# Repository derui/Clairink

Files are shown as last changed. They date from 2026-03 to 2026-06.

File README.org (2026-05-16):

* Clairink
This is a split keyboard having these features:

- ZMK firmware
- 3D printed keyboard case & Rotally encoder nob
  - You can manage behavior with ZMK
- Focus Thocky sound with the Lofree's Phantom switch
- all wireless
- able to use rechageable AAA battery x2
  - I use eneloop for this

* Bill Of Materials

| Name                                   | Qty |
|----------------------------------------+-----|
| SeeedStudio XIAO nRF52480              |   2 |
| AAA battery holder                     |   4 |
| M2 nut                                 |  12 |
| M2 screw                               |  12 |
| AE-XCL102D333CR-G                      |   2 |
| 1N4148W                                |  64 |
| Choc V2 Socket                         |  42 |
| Rotally Encoder (ALPS EC12 compatible) |   2 |
| SS-12D01G3                             |   2 |
| chip condenser (0.1uF)                 |   4 |
| chip register (2.2KΩ)                  |   4 |

* LICENSE
MIT

** LICENSE note
This keyboard uses Seeed Studio's XIAO nRF52480 kicad symbol and footprint. There are licensed under MIT that they written in [[https://wiki.seeedstudio.com/ja/License/][here]].

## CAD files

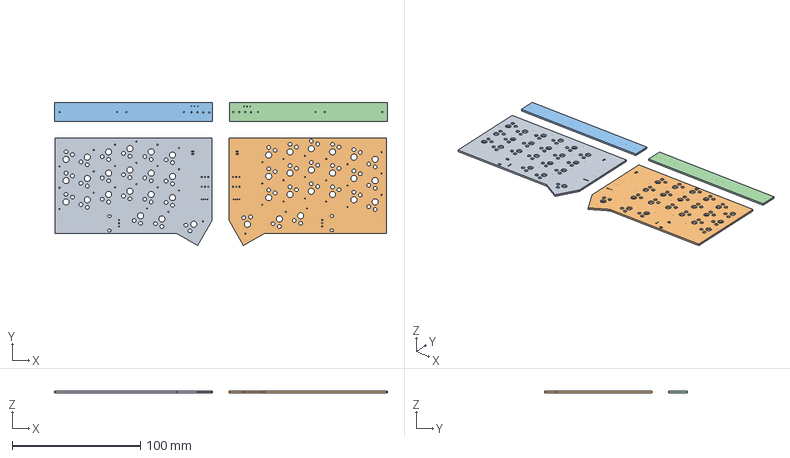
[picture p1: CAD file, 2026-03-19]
assemble.step
259.6 x 111.5 x 1.51 mm
assemble_PCB_1
assemble_PCB_2
assemble_PCB_3
assemble_PCB_4

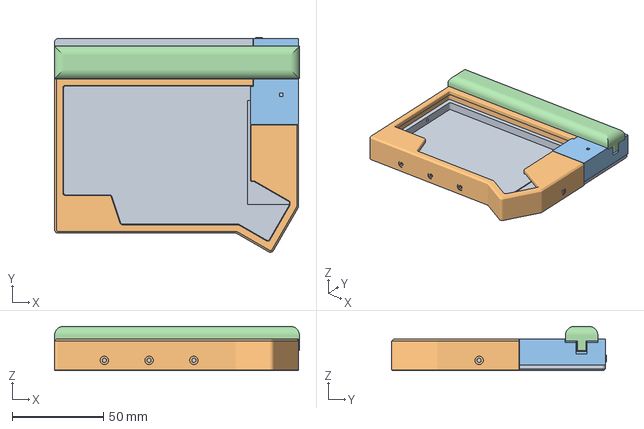
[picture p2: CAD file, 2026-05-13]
case-v1_3-finish.3mf
134.1 x 117.5 x 24.3 mm

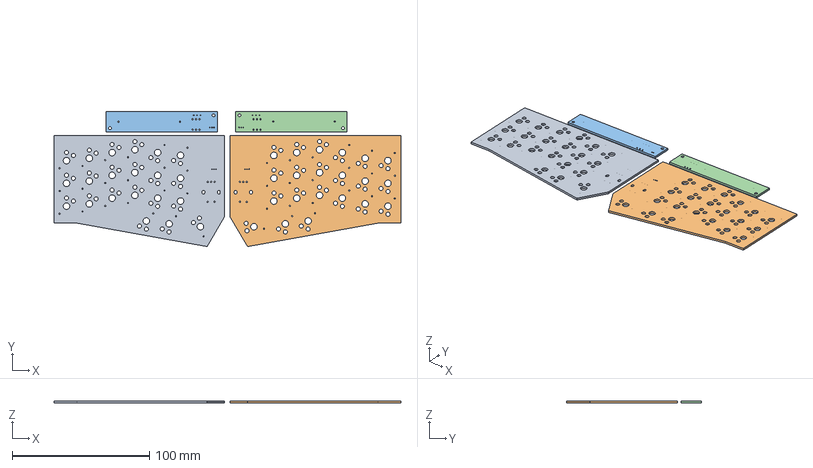
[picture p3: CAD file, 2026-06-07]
v2/assemble-final/base.step
252.6 x 98.4 x 1.51 mm
assemble_PCB_1
assemble_PCB_2
assemble_PCB_3
assemble_PCB_4

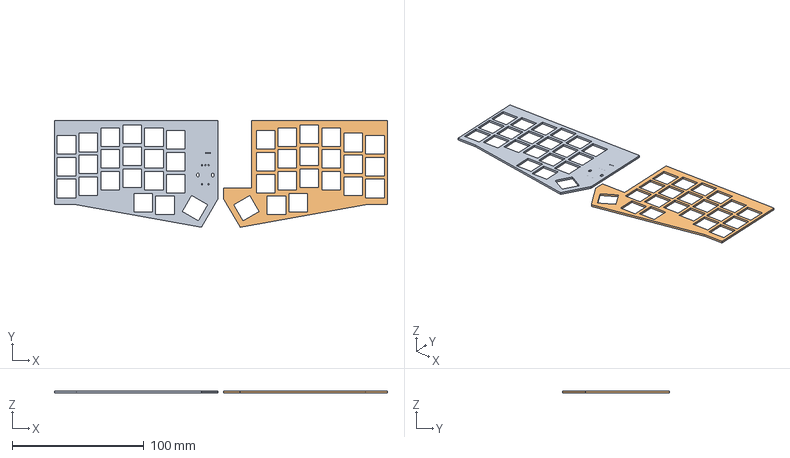
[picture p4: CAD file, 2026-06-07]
v2/switch-plate/base.step
252.6 x 80.8 x 1.51 mm
switch-plate_PCB_1
switch-plate_PCB_2

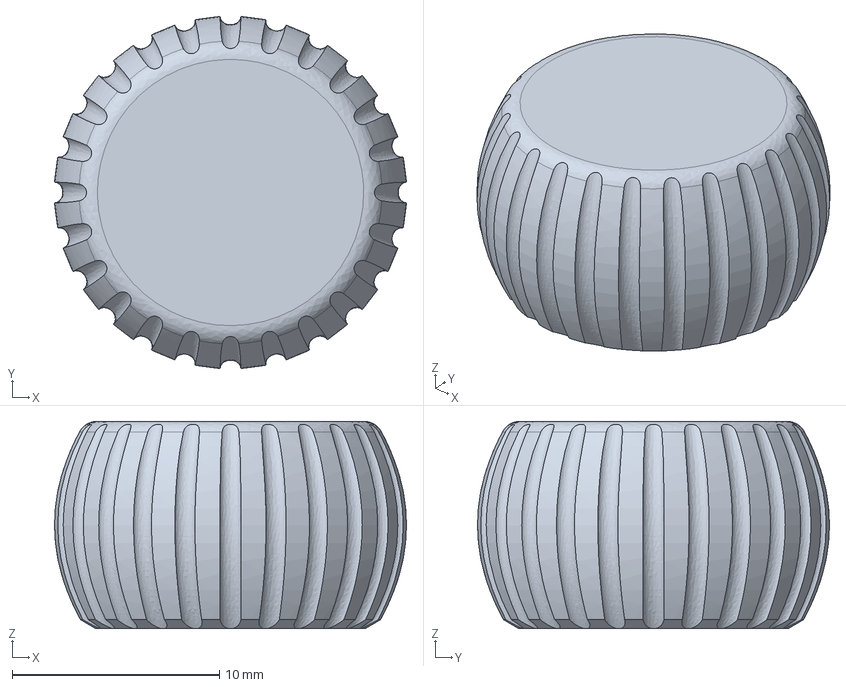
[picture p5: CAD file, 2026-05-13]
encoder-nob.FCStd
17.0 x 17.0 x 10.0 mm

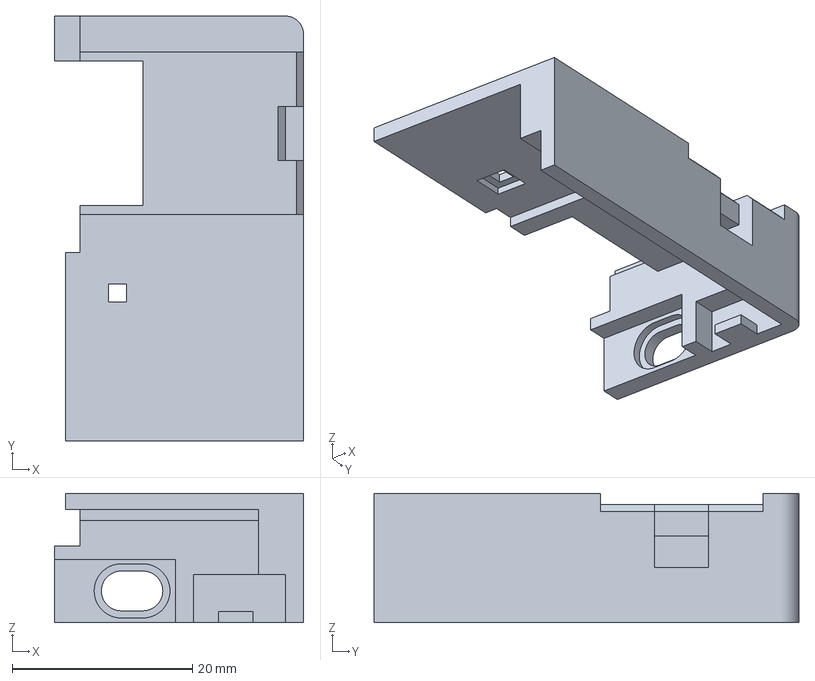
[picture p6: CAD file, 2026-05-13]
case-v1_3-finish_right-micom cover.3mf
27.6 x 47.1 x 14.3 mm

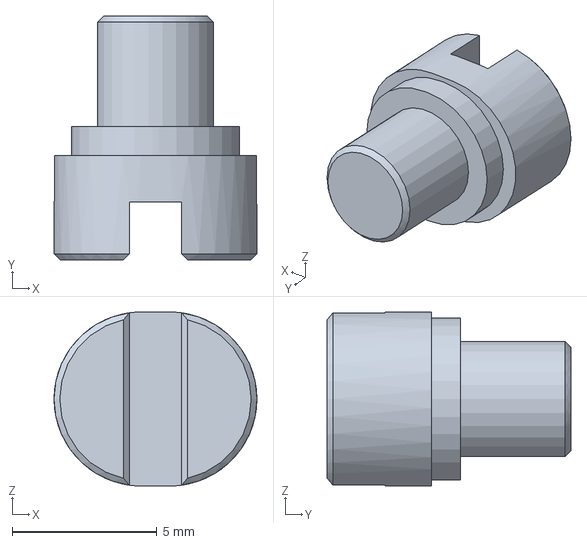
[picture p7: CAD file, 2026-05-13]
case-v1_3-finish-switch.3mf
7.00 x 8.40 x 6.00 mm

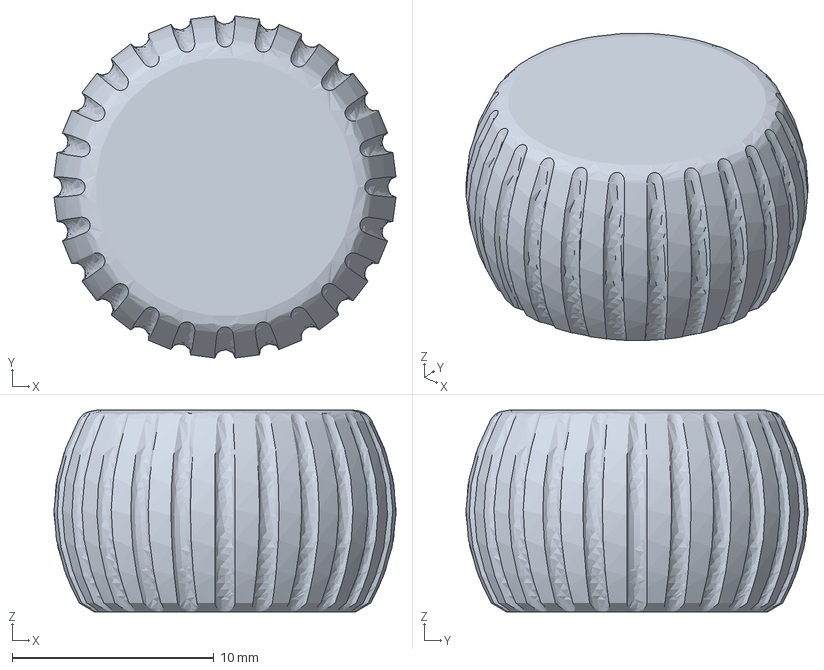
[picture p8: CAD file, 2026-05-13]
encoder-nob-Cut.3mf
17.0 x 17.0 x 10.0 mm

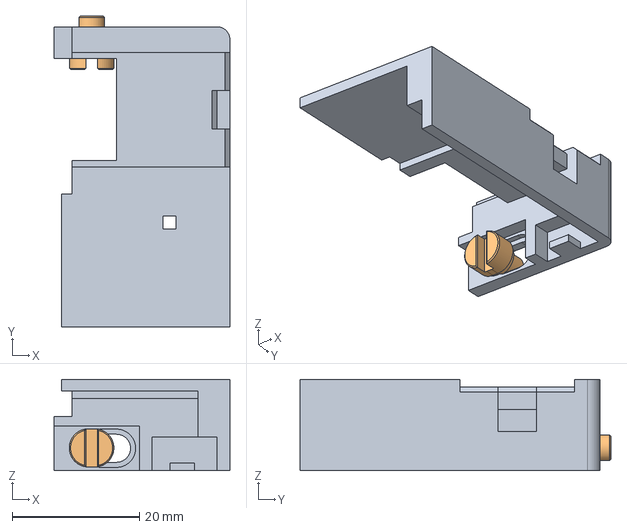
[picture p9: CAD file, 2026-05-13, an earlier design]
v1/case/case-v1_3-finish.FCStd
27.6 x 48.8 x 14.3 mm
micom cover
switch

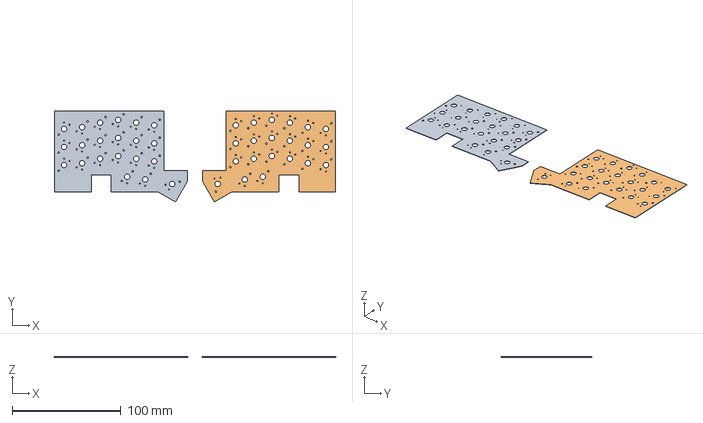
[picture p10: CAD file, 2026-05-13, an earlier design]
v1/switch-foam/switch-foam.step
258.6 x 83.7 x 0.31 mm
switch-foam_PCB_1
switch-foam_PCB_2

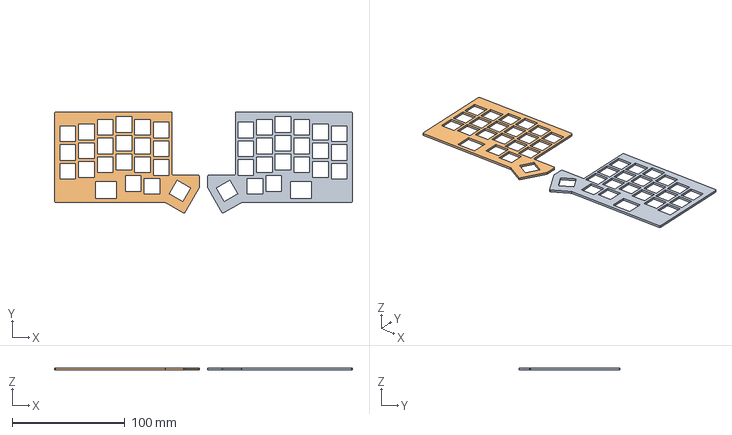
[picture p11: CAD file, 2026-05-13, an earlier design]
v1/switch-plate/switch-plate.step
264.6 x 89.9 x 1.91 mm
switch-plate_PCB_1
switch-plate_PCB_2

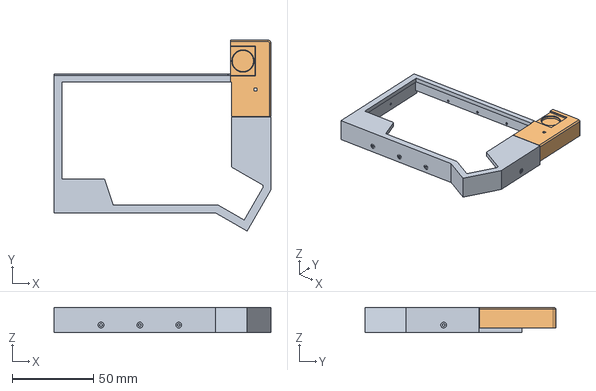
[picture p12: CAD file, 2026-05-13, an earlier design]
v1/case/case-v1-finish.FCStd
133.6 x 117.7 x 15.5 mm
top
micom cover

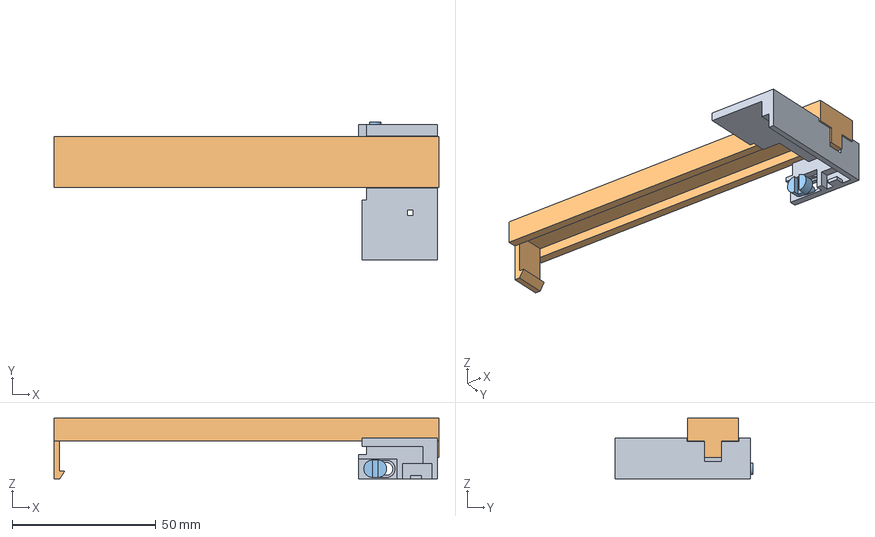
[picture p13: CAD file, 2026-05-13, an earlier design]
v1/case/case-v1_3.FCStd
134.1 x 48.0 x 21.2 mm
micom cover
battery cover
switch

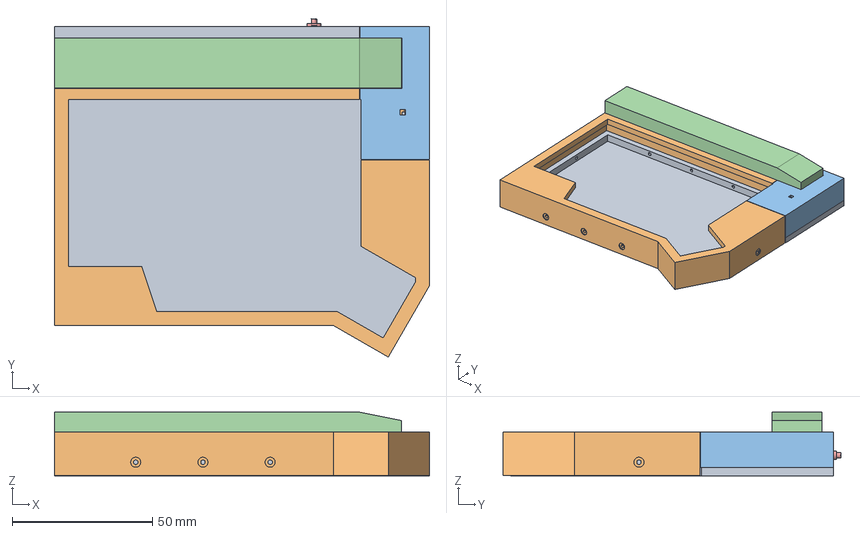
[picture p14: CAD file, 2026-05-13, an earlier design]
v1/case/case-v1.FCStd
133.6 x 120.5 x 22.7 mm
bottom
top
micom cover
battery cover
switch
BOSS-EXTRUDE14_8_
BOSS-EXTRUDE7_4_
BOSS-EXTRUDE7_3_
BOSS-EXTRUDE14_4_
BOSS-EXTRUDE14_2_
BOSS-EXTRUDE14_11_
BOSS-EXTRUDE7_7_
BOSS-EXTRUDE14_9_
BOSS-EXTRUDE14_3_
BOSS-EXTRUDE14_7_
MIRROR2
BOSS-EXTRUDE14_5_
BOSS-EXTRUDE14_12_
BOSS-EXTRUDE7_8_
BOSS-EXTRUDE7_1_
BOSS-EXTRUDE14_10_
BOSS-EXTRUDE7_9_
BOSS-EXTRUDE14_6_
BOSS-EXTRUDE14_1_
BOSS-EXTRUDE7_6_
BOSS-EXTRUDE7_2_
CUT-EXTRUDE5
BOSS-EXTRUDE7_5_
Shield
Pins
Pins001
Pins002
Pins003
CAP
CAP001
CAP002
ANT1
ANT001
ANT002
Silkscreen
Silkscreen001
Silkscreen002
Silkscreen003
Silkscreen004
Silkscreen005
Silkscreen006
Silkscreen007
Silkscreen008
Silkscreen009
Silkscreen010
Silkscreen011
Silkscreen012
CAP004
CAP005
CAP006
CAP 3
CAP 001
CAP 002
LED
LED001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

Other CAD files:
case-v1_3-finish-micom cover.3mf
v1/case/case-v1_2.FCStd
v1/case/case-v1_2-finish.FCStd
v1/case/case-v1_3-finish_right.FCStd
v1/case/case-v1_3-finish.3mf

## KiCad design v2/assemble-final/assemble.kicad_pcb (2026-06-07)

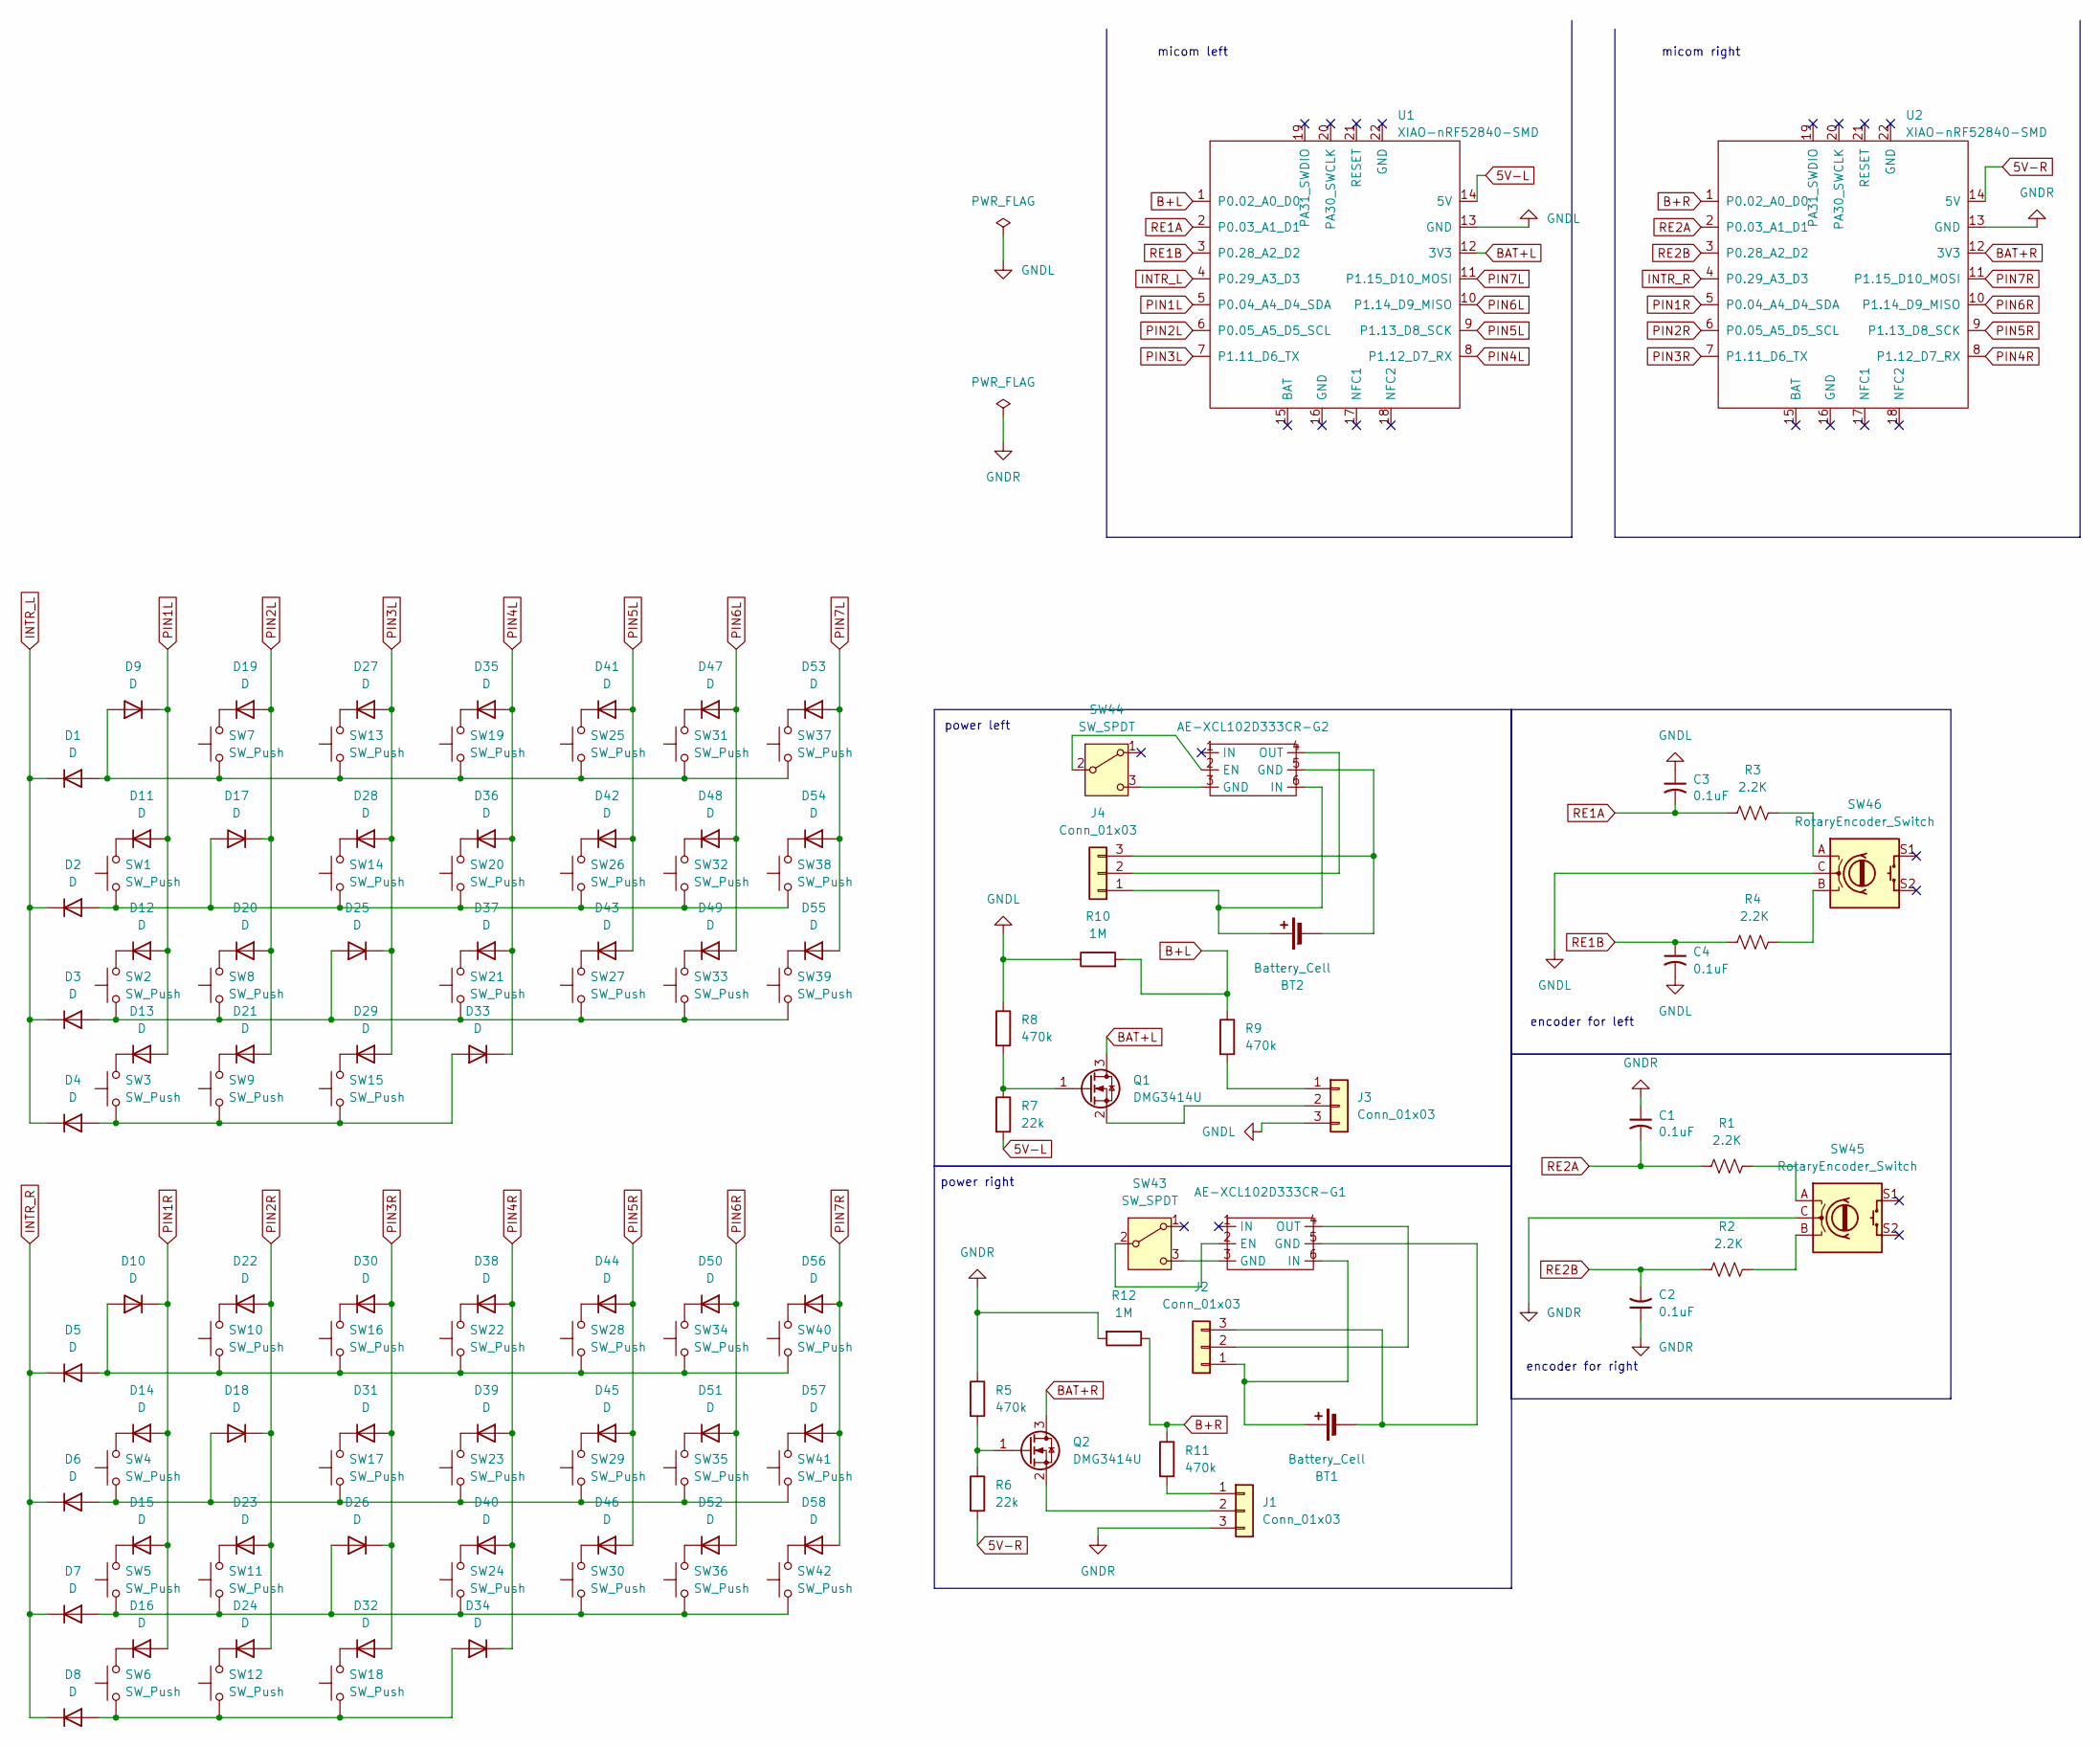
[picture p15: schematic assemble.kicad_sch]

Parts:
AE-XCL102D333CR-G1, AE-XCL102D333CR-G2: AE-XCL102D333CR-G
BT1, BT2: Battery_Cell; Battery_AAA
C1, C2, C3, C4: 0.1uF; C_0603_1608Metric_Pad1.08x0.95mm_HandSolder
D1, D2, D3, D4, D5, D6, D7, D8, D9, D10, D11, D12, D13, D14, D15, D16, D17, D18, D19, D20, D21, D22, D23, D24, D25, D26, D27, D28, D29, D30, D31, D32, D33, D34, D35, D36, D37, D38, D39, D40, D41, D42, D43, D44, D45, D46, D47, D48, D49, D50, D51, D52, D53, D54, D55, D56, D57, D58: D; Diode_SMD
J1, J2, J3, J4: Conn_01x03; JST_ZH_B3B-ZR_1x03_P1.50mm_Vertical
Q1, Q2: DMG3414U; SOT-23
R1, R2, R3, R4: 2.2K; R_0805_2012Metric_Pad1.20x1.40mm_HandSolder
R5, R8, R9, R11: 470k; R_0805_2012Metric_Pad1.20x1.40mm_HandSolder
R6, R7: 22k; R_0805_2012Metric_Pad1.20x1.40mm_HandSolder
R10, R12: 1M; R_0805_2012Metric_Pad1.20x1.40mm_HandSolder
SW1, SW2, SW3, SW4, SW5, SW6, SW7, SW8, SW9, SW10, SW11, SW12, SW13, SW14, SW15, SW16, SW17, SW18, SW19, SW20, SW21, SW22, SW23, SW24, SW25, SW26, SW27, SW28, SW29, SW30, SW31, SW32, SW33, SW34, SW35, SW36, SW37, SW38, SW39, SW40, SW41, SW42: SW_Push; Choc_v2_Hotswap_1u_16.6
SW43, SW44: SW_SPDT; TGSW_MSK-12D19
SW45, SW46: RotaryEncoder_Switch; RotaryEncoder_EC12E
U1, U2: XIAO-nRF52840-SMD

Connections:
5V-L: R7.2, U1.14 (5V)
5V-R: R6.2, U2.14 (5V)
B+L: R9.1, R10.2, U1.1 (P0.02_A0_D0)
B+R: R11.1, R12.1, U2.1 (P0.02_A0_D0)
BAT+L: Q1.3 (D), U1.12 (3V3)
BAT+R: Q2.3 (D), U2.12 (3V3)
GNDL: C3.1, C4.2, J3.3, R8.1, R10.1, SW46.C, U1.13 (GND)
GNDR: C1.1, C2.1, J1.3, R5.1, R12.2, SW45.C, U2.13 (GND)
INTR_L: D1.1 (K), D2.1 (K), D3.1 (K), D4.1 (K), U1.4 (P0.29_A3_D3)
INTR_R: D5.1 (K), D6.1 (K), D7.1 (K), D8.1 (K), U2.4 (P0.29_A3_D3)
unnamed: AE-XCL102D333CR-G1.2 (EN), SW43.2 (B)
unnamed: AE-XCL102D333CR-G1.4 (OUT), J2.2
unnamed: AE-XCL102D333CR-G2.2 (EN), SW44.2 (B)
unnamed: AE-XCL102D333CR-G2.4 (OUT), J4.2
unnamed: AE-XCL102D333CR-G1.6 (IN), BT1.1 (+), J2.1
unnamed: AE-XCL102D333CR-G1.5 (GND), BT1.2 (-), J2.3
unnamed: AE-XCL102D333CR-G2.6 (IN), BT2.1 (+), J4.1
unnamed: AE-XCL102D333CR-G2.5 (GND), BT2.2 (-), J4.3
unnamed: D1.2 (A), D9.2 (A), SW7.1, SW13.1, SW19.1, SW25.1, SW31.1, SW37.1
unnamed: D5.2 (A), D10.2 (A), SW10.1, SW16.1, SW22.1, SW28.1, SW34.1, SW40.1
unnamed: D11.1 (K), SW1.2
unnamed: D12.1 (K), SW2.2
unnamed: D13.1 (K), SW3.2
unnamed: D14.1 (K), SW4.2
unnamed: D15.1 (K), SW5.2
unnamed: D16.1 (K), SW6.2
unnamed: D2.2 (A), D17.2 (A), SW1.1, SW14.1, SW20.1, SW26.1, SW32.1, SW38.1
unnamed: D6.2 (A), D18.2 (A), SW4.1, SW17.1, SW23.1, SW29.1, SW35.1, SW41.1
unnamed: D19.1 (K), SW7.2
unnamed: D20.1 (K), SW8.2
unnamed: D21.1 (K), SW9.2
unnamed: D22.1 (K), SW10.2
unnamed: D23.1 (K), SW11.2
unnamed: D24.1 (K), SW12.2
unnamed: D3.2 (A), D25.2 (A), SW2.1, SW8.1, SW21.1, SW27.1, SW33.1, SW39.1
unnamed: D7.2 (A), D26.2 (A), SW5.1, SW11.1, SW24.1, SW30.1, SW36.1, SW42.1
unnamed: D27.1 (K), SW13.2
unnamed: D28.1 (K), SW14.2
unnamed: D29.1 (K), SW15.2
unnamed: D30.1 (K), SW16.2
unnamed: D31.1 (K), SW17.2
unnamed: D32.1 (K), SW18.2
unnamed: D4.2 (A), D33.2 (A), SW3.1, SW9.1, SW15.1
unnamed: D8.2 (A), D34.2 (A), SW6.1, SW12.1, SW18.1
unnamed: D35.1 (K), SW19.2
unnamed: D36.1 (K), SW20.2
unnamed: D37.1 (K), SW21.2
unnamed: D38.1 (K), SW22.2
unnamed: D39.1 (K), SW23.2
unnamed: D40.1 (K), SW24.2
unnamed: D41.1 (K), SW25.2
unnamed: D42.1 (K), SW26.2
unnamed: D43.1 (K), SW27.2
unnamed: D44.1 (K), SW28.2
unnamed: D45.1 (K), SW29.2
unnamed: D46.1 (K), SW30.2
unnamed: D47.1 (K), SW31.2
unnamed: D48.1 (K), SW32.2
unnamed: D49.1 (K), SW33.2
unnamed: D50.1 (K), SW34.2
unnamed: D51.1 (K), SW35.2
unnamed: D52.1 (K), SW36.2
unnamed: D53.1 (K), SW37.2
unnamed: D54.1 (K), SW38.2
unnamed: D55.1 (K), SW39.2
unnamed: D56.1 (K), SW40.2
unnamed: D57.1 (K), SW41.2
unnamed: D58.1 (K), SW42.2
unnamed: J1.1, R11.2
unnamed: J1.2, Q2.2 (S)
unnamed: J3.1, R9.2
unnamed: J3.2, Q1.2 (S)
unnamed: Q1.1 (G), R7.1, R8.2
unnamed: Q2.1 (G), R5.2, R6.1
unnamed: R1.2, SW45.A
unnamed: R2.2, SW45.B
unnamed: R3.2, SW46.A
unnamed: R4.2, SW46.B
unnamed: AE-XCL102D333CR-G1.3 (GND), SW43.3 (C)
unnamed: AE-XCL102D333CR-G2.3 (GND), SW44.3 (C)
PIN1L: D9.1 (K), D11.2 (A), D12.2 (A), D13.2 (A), U1.5 (P0.04_A4_D4_SDA)
PIN1R: D10.1 (K), D14.2 (A), D15.2 (A), D16.2 (A), U2.5 (P0.04_A4_D4_SDA)
PIN2L: D17.1 (K), D19.2 (A), D20.2 (A), D21.2 (A), U1.6 (P0.05_A5_D5_SCL)
PIN2R: D18.1 (K), D22.2 (A), D23.2 (A), D24.2 (A), U2.6 (P0.05_A5_D5_SCL)
PIN3L: D25.1 (K), D27.2 (A), D28.2 (A), D29.2 (A), U1.7 (P1.11_D6_TX)
PIN3R: D26.1 (K), D30.2 (A), D31.2 (A), D32.2 (A), U2.7 (P1.11_D6_TX)
PIN4L: D33.1 (K), D35.2 (A), D36.2 (A), D37.2 (A), U1.8 (P1.12_D7_RX)
PIN4R: D34.1 (K), D38.2 (A), D39.2 (A), D40.2 (A), U2.8 (P1.12_D7_RX)
PIN5L: D41.2 (A), D42.2 (A), D43.2 (A), U1.9 (P1.13_D8_SCK)
PIN5R: D44.2 (A), D45.2 (A), D46.2 (A), U2.9 (P1.13_D8_SCK)
PIN6L: D47.2 (A), D48.2 (A), D49.2 (A), U1.10 (P1.14_D9_MISO)
PIN6R: D50.2 (A), D51.2 (A), D52.2 (A), U2.10 (P1.14_D9_MISO)
PIN7L: D53.2 (A), D54.2 (A), D55.2 (A), U1.11 (P1.15_D10_MOSI)
PIN7R: D56.2 (A), D57.2 (A), D58.2 (A), U2.11 (P1.15_D10_MOSI)
RE1A: C3.2, R3.1, U1.2 (P0.03_A1_D1)
RE1B: C4.1, R4.1, U1.3 (P0.28_A2_D2)
RE2A: C1.2, R1.1, U2.2 (P0.03_A1_D1)
RE2B: C2.2, R2.1, U2.3 (P0.28_A2_D2)

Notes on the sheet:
encoder for right
encoder for left
micom right
power left
power right
micom left

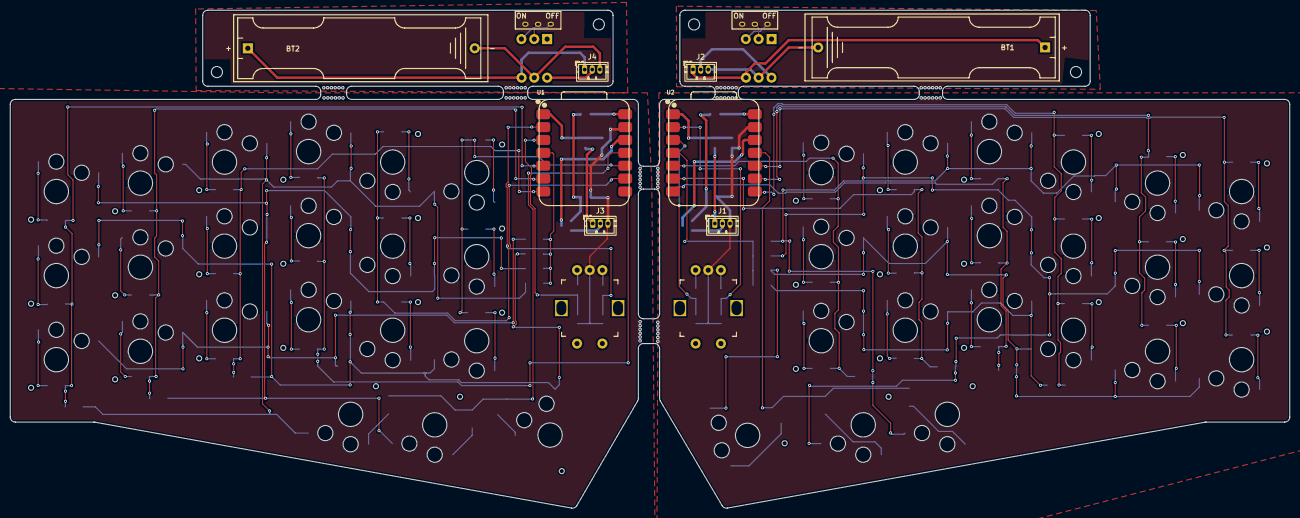
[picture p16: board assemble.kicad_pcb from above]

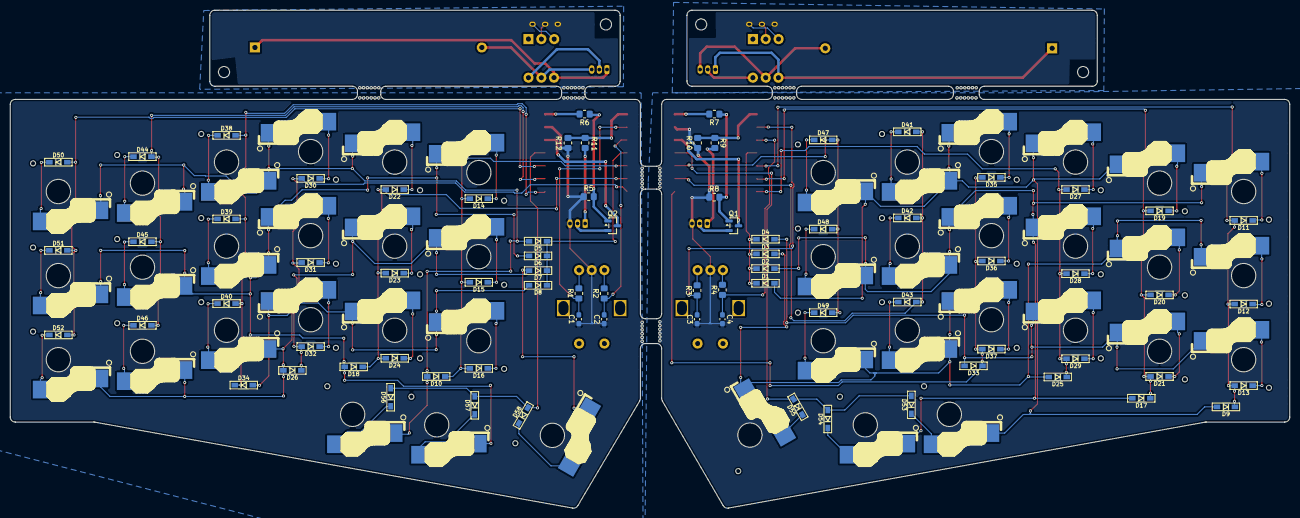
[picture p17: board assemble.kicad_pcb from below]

Board: 2 copper layers, 252.6 x 98.3 mm, 148 parts (18 on the bottom side), 98 nets.

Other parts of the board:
Ref**: Val**; m2_Screw_Hole
Ref**#2, Ref**#5, Ref**#6, Ref**#8, Ref**#9, Ref**#10, Ref**#11, Ref**#12, Ref**#13, Ref**#14, Ref**#15, Ref**#16: Val**; Mouse_Bite_Hole
Ref**#3, Ref**#4, Ref**#7: Val**; m2_Screw_Hole

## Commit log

2026-03-08 feat: readme and base assembles
    [assemble.kicad_pcb, assemble.kicad_sch, assemble.step]
2026-03-09 feat: add some rotary encoder
    [assemble.kicad_sch]
2026-03-15 wip: implement PCB
    [assemble.kicad_pcb, assemble.kicad_sch]
2026-03-19 fix: move pcb
    [assemble.kicad_pcb, assemble.step]
2026-03-23 fix: add screw hole
    [assemble.kicad_pcb]
2026-04-01 feat: add case base
    [case.FCStd]
2026-04-05 feat: add switch plate
    [assemble.step, key-plate.kicad_pcb]
2026-04-05 fix: add GND pattern
    [assemble.kicad_pcb]
2026-04-05 fix: rename
    [assemble.step, switch-plate.kicad_pcb]
2026-04-14 feat: update kicad
    [assemble.kicad_pcb, case.FCStd, switch-plate.kicad_pcb]
2026-05-13 feat: add v1.2 and v1.3
    [assemble-finish-B_Cu.gbr, assemble-finish-B_Mask.gbr, assemble-finish-B_Paste.gbr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]
2026-05-16 refactor: move files
    [assemble-finish-B_Cu.gbr, assemble-finish-B_Mask.gbr, assemble-finish-B_Paste.gbr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]
2026-05-24 feat: implement v2 assemble
    [assemble.kicad_pcb, assemble.kicad_sch]
2026-06-05 feat: update some pins
    [assemble.kicad_pcb]
2026-06-07 feat: finalize v2
    [assemble.kicad_pcb, assemble.kicad_sch, base.step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]
